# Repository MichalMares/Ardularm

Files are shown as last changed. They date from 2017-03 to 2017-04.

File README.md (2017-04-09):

# Ardularm

Ardularm is a proof-of-concept project which focuses on making an inexpensive alarm based on the Arduino platform.   
[GitHub Repository](https://github.com/MichalMares/Ardularm)

## Components and Wiring

Scheme:

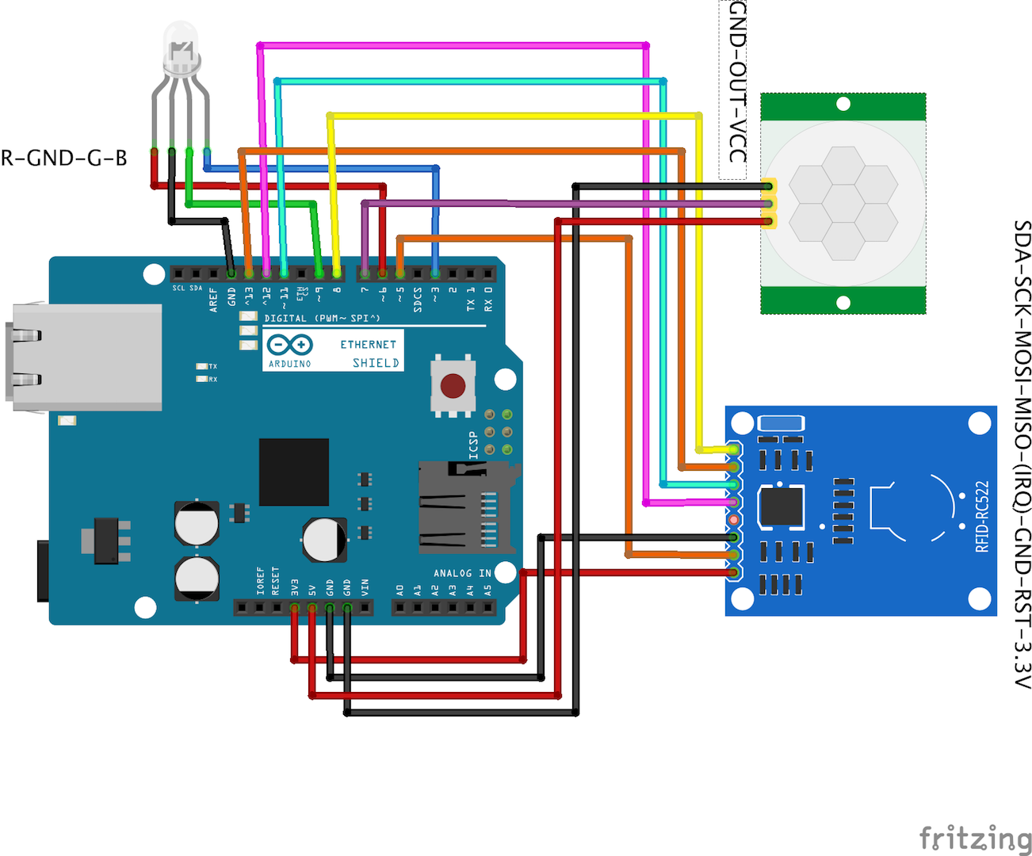
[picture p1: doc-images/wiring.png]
Wiring


You can also view this scheme in the Fritzing programme (`Wiring.fzz`).

Used components:
* Arduino UNO Rev3
* Ethernet Shield R3
* RFID Reader RC522
* Passive Infrared Sensor HC-SR501 
* Generic RGB Diode

Other components might work as well (not tested).

## Installation

Ardularm had been developed with Arduino IDE (for the Arduino code) and any other editor (for the server-side PHP code). Libraries [AddicoreRFID](http://www.addicore.com/v/vspfiles/downloadables/Product%20Downloadables/RFID_RC522/AddicoreRFID.zip)* and [Bootstrap framework](http://getbootstrap.com/) were used while creating this. To run this project on your own, there are a few steps necessary:

1. Create a database and an e-mail box on your hosting.
2. Fill in the settings file with the right credentials for your database in `Server\template.config.php` and save it as `Server\config.php`.
3. Create a `Server\.htpasswd` file with your desired user name and password (https://faq.oit.gatech.edu/content/how-do-i-do-basicauth-using-htaccess-and-htpasswd), edit path in `Server\template.htaccess` file and save it as `.htaccess`. ".htaccess" works for Apache servers only!
4. Upload the content of `Server` onto your server.
5. Run the `Server\create.php` script. This will create all the tables needed for the project and necessary values.
6. Wire up your Arduino UNO according to "Components and Wiring" section of this document.
7. Fill in the variables in `Arduino\Ardularm\Ardularm.ino` under the comment "user-configurable".
8. Upload `Arduino\Ardularm\Ardularm.ino` on your Arduino UNO using the Arduino IDE.
9. Repeat steps 6, 7, 8 for each unit you want to connect.
10. Enjoy your extra safety.

Ardularm had been developed running an Apache server with MySQL database. However, PDO should ensure it works on other SQL databases as well (not tested).

Arduino's (`Ardularm.ino`) and server's (`config.php`) "key" must correspond and can not be empty. It ensures that the POST requests come directly from the Arduino unit. If you use multiple Arduinos, "key" has to be the same for all of them.

\* The AddicoreRFID library had to be edited in order to work with Ethernet shield.

## How to use Ardularm?

**Turn alarm on/off**   
Trusted card has to be used to toggle the state. When the alarm is on the diode turns red, when off it is green (as a traffic light - green means you can enter).

**Add/remove a card to/from trusted**   
First, MasterTag has to be detected and the diode turns blue. Then you can scan your card and it will be added as trusted, if it was not trusted befor. BEWARE: If your card already is trusted, it will be REMOVED.

**Viewing the log**   
Log is located on the page `../dash.php`. Entries are sorted from newest to oldest. To search in between specific dates, enter them and click "search". If you want to leave the page running and see new entries without refreshing the page, just tick the "autorefresh" checkbox. This will refresh the page atomatically every 5 seconds.

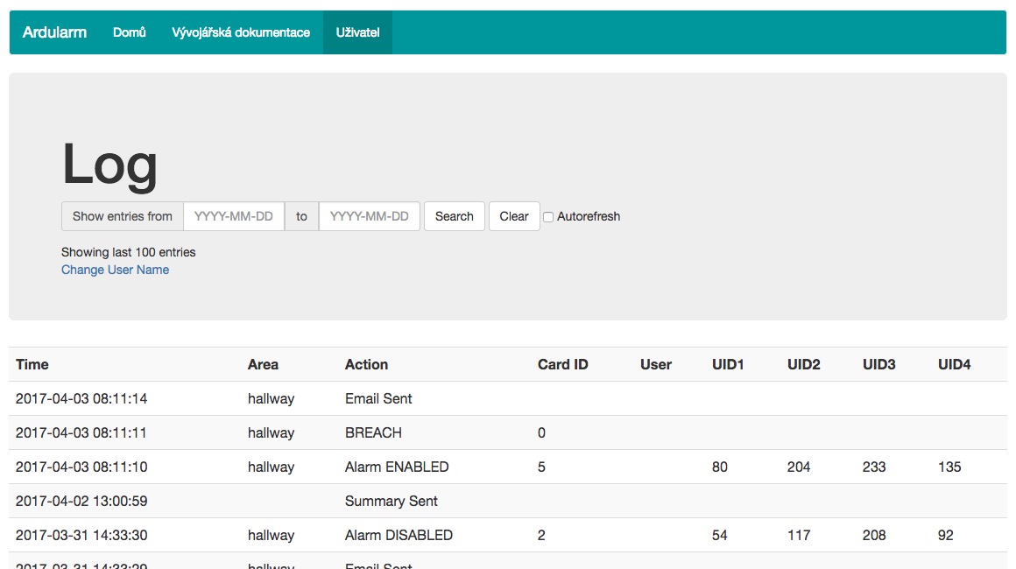
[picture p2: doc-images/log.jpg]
Log


**Editing card name**
Under the date selection on the log page, click the button "Change User Name". All four IDs must be filled in order to change the name. Successful change will be confirmed at the end of the paragraph.

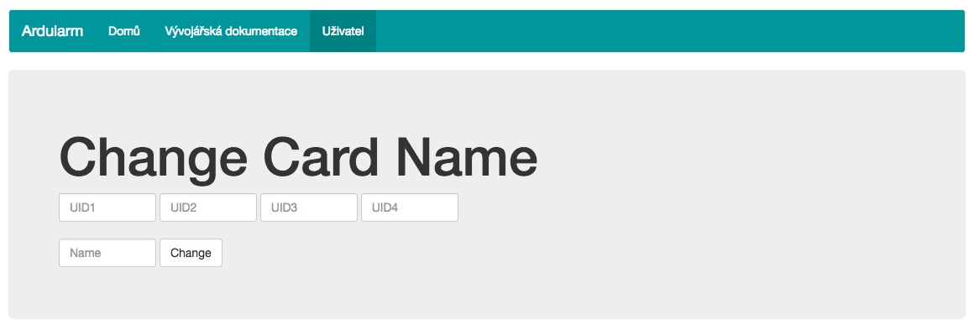
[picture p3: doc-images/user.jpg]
User


## Result

When done correctly, final product should look something like this:

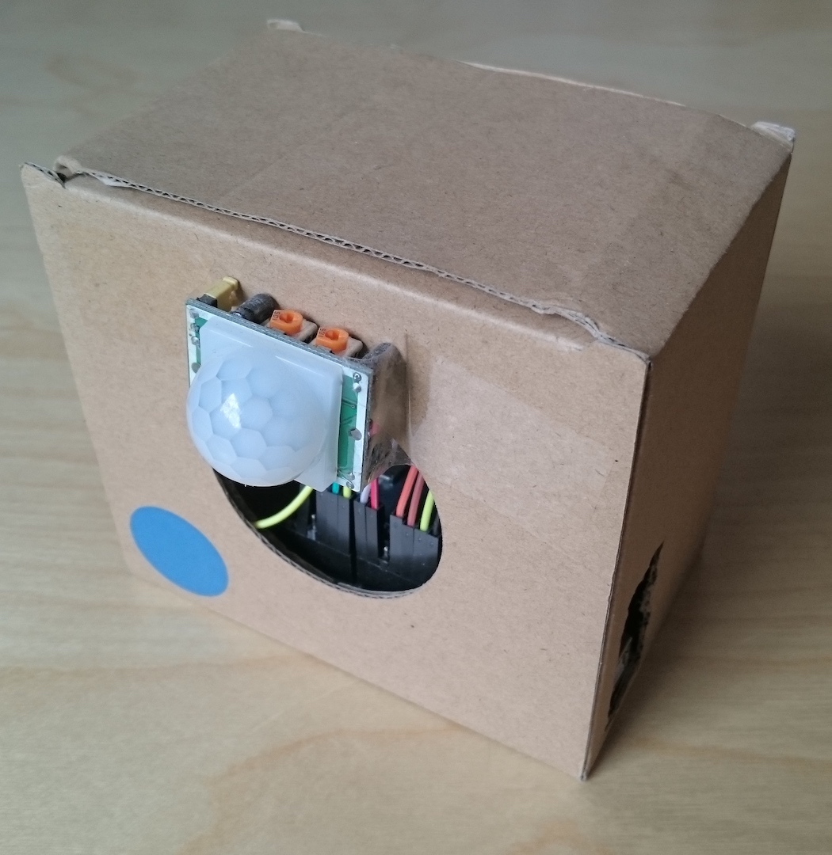
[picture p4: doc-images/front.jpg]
Front

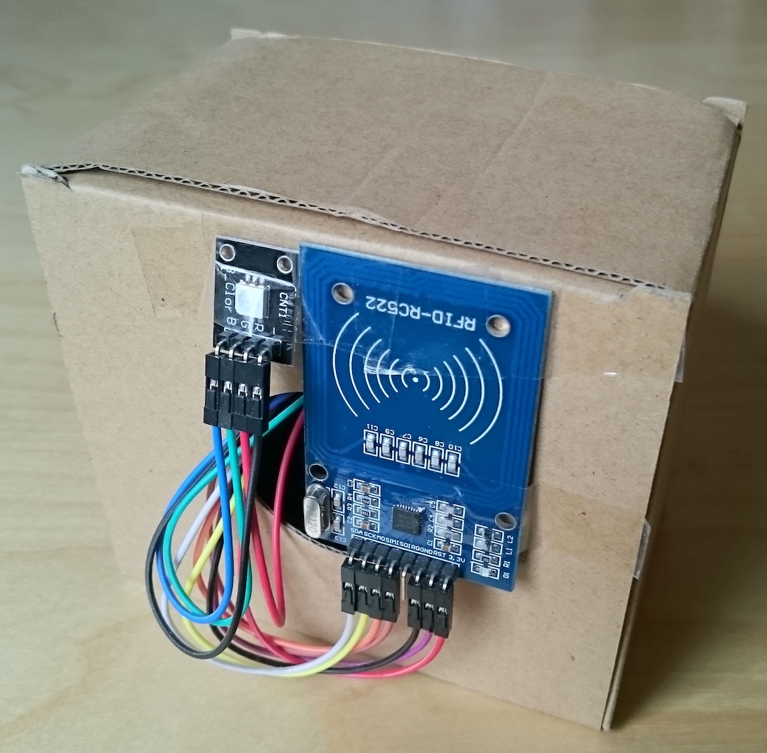
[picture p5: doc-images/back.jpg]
Back

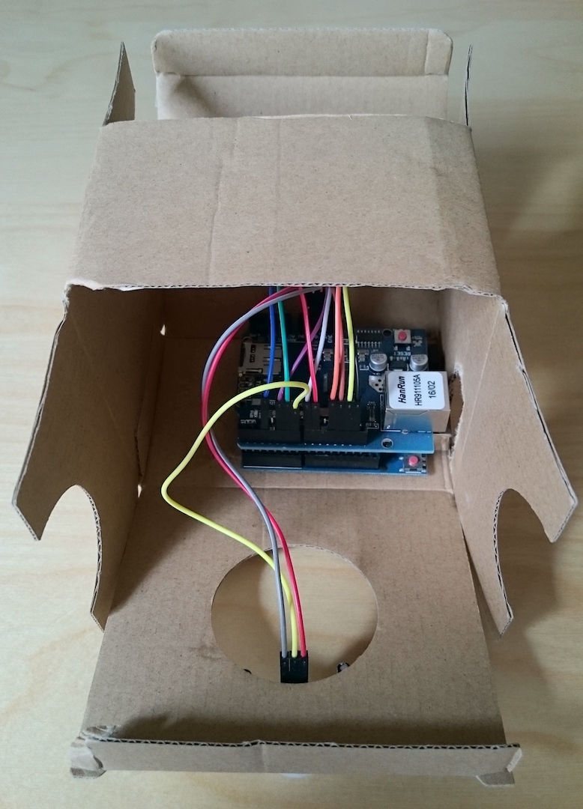
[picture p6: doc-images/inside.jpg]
Inside


The PIR sensor should face the area you want to secure and RFID reader with LED should be accessable without entering it. Of course, wires can be lengthened and mechanically protected in order to achieve this result.

## For Developers

Ardularm consists of three main parts.   
The first one is the code for Arduino unit (`Arduino\Ardularm\Ardularm.ino`), which works just like any other Arduino sketch - there is a setup() method which runs once and loop() method, which cycles for the rest of the time, running the code and calling the other methods.   
Second are the API's, which take care of the communication between Arduino and the database (`Server\api\`).   
Last is the dashboard (`Server\dash.php`) which shows the log to the user and enables some basic sorting and changing the name of the cards (`Server\user.php`).

In-depth documentation can be found in `Server\DoxyDoc\`.

Code posted here can be further developed.   
If you would like to make it work on a different Arduino board, change pin definitions at the beginning of `Arduino\Ardularm\Arduino.ino`. Mainly, SPI pins (which are pre-defined) must be changed and then connected accordingly.   
Buzzer extension is also possible: add a tone(pin, frequency) method into the `if (digitalRead(pirPin) == HIGH)` block of code and noTone() after it. [Documentation of tone()](https://www.arduino.cc/en/reference/tone)   
To send a SMS alert instead of an email, you will need something like a GSM/GPRS Shield. Instead of calling `post("sendMail", "");` in `if (digitalRead(pirPin) == HIGH)` block, you will then use sms.print() method to send a SMS according to the [official tutorial](https://www.arduino.cc/en/Tutorial/GSMExamplesSendSMS) on sending SMS.

## License

[MIT](https://github.com/MichalMares/Ardularm/blob/master/LICENSE.txt) @ [Michal Mareš](https://github.com/MichalMares)

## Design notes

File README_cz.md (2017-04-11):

# Ardularm

Ardularm je projekt, který se zabývá vytvořením levného domácího alarmu prostřednictvím platformy Arduino.   
[Repozitář na GitHubu](https://github.com/MichalMares/Ardularm)

## Komponenty a zapojení

Schéma zapojení:

Wiring

Použité součástky:
* Arduino UNO Rev3
* Ethernet Shield R3
* RFID Reader RC522
* Passive Infrared Sensor HC-SR501 
* Generic RGB Diode

Jiné součástky mohou také fungovat (netestováno).

## Instalace

Ardularm byl vytvořen pomocí Arduino IDE (kód pro Arduino) a dalším editorem (pro serverovou část, PHP kód). Knihovny [AddicoreRFID](http://www.addicore.com/v/vspfiles/downloadables/Product%20Downloadables/RFID_RC522/AddicoreRFID.zip)* a [Bootstrap framework](http://getbootstrap.com/) byly využity při vývoji. Pro instalaci projektu je potřeba:

1. Vytvořte databázi a e-mailovou schránku na vašem hostingu.
2. Upravte a vyplňte `Server\template.config.php` a uložte soubor jako `Server\config.php`.
3. Vytvořte soubor `Server\.htpasswd` se zvoleným uživatelským jménem a heslem (https://faq.oit.gatech.edu/content/how-do-i-do-basicauth-using-htaccess-and-htpasswd), přepište cestu v `Server\template.htaccess` a uložte soubor jako `.htaccess`. Zabezpečení přes htaccess platí pouze pro servery Apache!
4. Nahrajte obsah adresáře `Server` na server.
5. Spusťte `Server\create.php`. Tím automaticky vytvoříte tabulky databáze potřebné pro fungování Ardularmu.
6. Zapojte vaše Arduino UNO podle sekce "Komponenty a zapojení".
7. Vyplňte proměnné v `Arduino\Ardularm\Ardularm.ino` pod komentářem "user-configurable".
8. Nahrajte `Arduino\Ardularm\Ardularm.ino` na vaše Arduino UNO prostřednictvím Arduino IDE.
9. Opakujte kroky 6, 7, 8 pro každé zařízení, které si přejete připojit.
10. Užívejte si pocit bezpečí.

Ardularm byl vyvinut na Apache serveru s MySQL databází, nicméně PDO by mělo zajistit kompatibilitu s ostatními SQL databázemi (netestováno).

Klíč "key" Arduina (`Ardularm.ino`) musí souhlasit s klíčem severu (`config.php`) a nemůže být prázdný. Zajišťuje, že komunikace POST requestem pochází přímo z Arduina. Při použití více Arduin musí být klíče na všech stejné.

\* Knihovna AddicoreRFID musela být modifikována, aby fungovala paralelně s Ethernet Shield.

## Návod k použití

**Zapnutí/vypnutí alarmu**   
Pouze důvěryhodné karty mohou přepínat stav alarmu. Pokud je alarm aktivní, svítí červeně, pokud neaktivní, zeleně (jako semafor - zelená znamená, že můžete projít).

**Přidat/odebrat kartu do/z důvěryhodných**   
Nejdříve je potřeba načíst MasterTag (administrátorská karta) a vyčkat, než se dioda rozsvítí modře. Pak lze načíst další kartu, která bude zaevidována jako důvěryhodná, pokud předtím nebyla. POZOR: Pokud karta již byla důvěryhodná, bude z důvěryhodných ODEBRÁNA.

**Zobrazení událostí**   
Zobrazení událostí je možné v logu na `../dash.php`. Záznamy jsou seřazeny od nejnovějšího po nejstarší. Pro vyhledání v určitém časovém období, vyplňte data a stiskněte tlačítko "search". Pokud chcete stránku nechat spuštěnou a vidět nové záznamy, zatrhněte "atorefresh". Stránka se pak bude obnovovat s frekvencí 5 sekund.

Log

**Změna jména karty**
Pod výběrem data u logu klikněte na "Change User Name". Všechny čtyři identifikační čísla musí být vyplněny, aby mohlo být změněno jméno. Úspěšná změna bude potvrzena oznámením na konci odstavce.

User

## Výsledek

Při správném postupu by měl konečný výtvor vypadat podobně:

Front
Back
Inside

Infračervený senzor by měl směřovat do prostoru, který si přejete zajistit, RFID čtečka spolu s LED by pak měla být přístupná bez narušení tohoto prostoru. Vodiče mohou být samozřejmě prodlouženy a mechanicky chráněny pro dosažení takového výsledku.

## Licence

[MIT](https://github.com/MichalMares/Ardularm/blob/master/LICENSE.txt) @ [Michal Mareš](https://github.com/MichalMares)

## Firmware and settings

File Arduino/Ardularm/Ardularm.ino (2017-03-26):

/**
 * @file Ardularm.ino
 * @Author Michal Mareš
 * @date March, 2017
 * @brief The code running on Arduino unit.
 */

#include <AddicoreRFID.h>
#include <Ethernet.h>
#include <SPI.h>

// user-configurable
char server[] = "domain.tld"; /// Domain.
String key = "password"; /// Password for running PHP scripts.
String area = "location"; /// Location of this Ardularm.
int masterTag[] = {255, 255, 255, 255}; /// UIDs of the MasterTag.
byte mac[] = {0x00, 0xAA, 0xBB, 0xCC, 0x2E, 0x02}; /// Arduino Mac Address.

boolean alarmState = false; // beginning state of the alarm
unsigned long previousMillis = 0; // will store last time of checking the server
const long interval = 30000; // interval at which to act (in milliseconds)

// RGB LED pins
#define red 6
#define green 9
#define blue 3

// RFID variables
#define uchar unsigned char
#define uint  unsigned int
#define MAX_LEN 16 // maximum length of the RFID array
uchar fifobytes;
uchar fifoValue;

AddicoreRFID myRFID;
EthernetClient client;

const int ssSD = 4; // SD slave select pin
const int ssEthernet = 10; // Ethernet chip slave select pin
const int chipSelectPin = 8; // RFID slave select pin
const int NRSTPD = 5; // RFID reset pin
const int pirPin = 7; // PIR sensor pin

void setup() {
  Serial.begin(9600);
  SPI.begin();

  Serial.println("Initializing...");

  // enable PIR sensor
  pinMode(pirPin, INPUT);
  digitalWrite(pirPin, LOW);

  // start RFID reader
  pinMode(chipSelectPin, OUTPUT); // set digital pin 8 as OUTPUT to connect it to the RFID /ENABLE pin
  digitalWrite(chipSelectPin, LOW);
  pinMode(NRSTPD, OUTPUT); // set digital pin 5 , not reset and power-down
  digitalWrite(NRSTPD, HIGH);
  myRFID.AddicoreRFID_Init();

  // disable SD card
  pinMode(ssSD, OUTPUT);
  digitalWrite(ssSD, HIGH);

  // start Ethernet connection
  if (Ethernet.begin(mac) == 0) {
    Serial.println("Failed to configure Ethernet using DHCP");
  }
  delay(1000);

  printIPAddress();
  manageState("sync");
  post("addEntry", "action=Power ON");
  
  Serial.println("--- READY ---");
  Serial.println();
}

void loop() {
  uchar i, tmp;
  uchar status;
  uchar str[MAX_LEN];
  uchar RC_size;
  uchar blockAddr;  // Selection operation block address 0 to 63
  String mynum = "";
  str[1] = 0x4400;

  status = myRFID.AddicoreRFID_Request(PICC_REQIDL, str); // find tags, return tag type
  status = myRFID.AddicoreRFID_Anticoll(str); // anti-collision, return tag serial number 4 bytes

  if (status == MI_OK) {
    int sourceTag[] = {str[0], str[1], str[2], str[3], str[4]};

    // MasterTag detected and alarm is not on
    if (checkMaster(sourceTag) == true && alarmState == false) {
      Serial.println("MasterTag detected, waiting for another tag...");
      led(0,0,50);
      myRFID.AddicoreRFID_Halt();
      str[1] = 0x4400;
      while (status == MI_OK) {
        status = myRFID.AddicoreRFID_Request(PICC_REQIDL, str);
        status = myRFID.AddicoreRFID_Anticoll(str);
      }
      delay(1000);
      while (status != MI_OK) {
        status = myRFID.AddicoreRFID_Request(PICC_REQIDL, str);
        status = myRFID.AddicoreRFID_Anticoll(str);
      }

      if (status == MI_OK) {
        led(50,50,0);
        int sourceTag[] = {str[0], str[1], str[2], str[3], str[4]};
        readTag(sourceTag);

        String data = "uid1=" + String(sourceTag[0]) + "&uid2=" + String(sourceTag[1]) + "&uid3=" + String(sourceTag[2]) + "&uid4=" + String(sourceTag[3]);
        post("manageTags", data); // pass tag to the manageTags.php script
      }
    }

    // normal tag detected
    else {
      readTag(sourceTag);
      led(50,50,0);
      Serial.print("Is tag trusted? ");
      boolean trusted = verifyTrusted(sourceTag); // check if tag is trusted or not
      if (trusted == true) {
        alarmToggle(sourceTag); // trusted -> toggle alarm
      }
      else if (trusted == false) {
        String action = "Access DENIED";
        String data = "uid1=" + String(sourceTag[0]) + "&uid2=" + String(sourceTag[1]) + "&uid3=" + String(sourceTag[2]) + "&uid4=" + String(sourceTag[3]) + "&action=" + String(action);
        post("addEntry", data); // not trusted -> add entry to db
      }
    }
    Serial.println();
    delay(500);
  }

  myRFID.AddicoreRFID_Halt(); // Command tag into hibernation

  // check server for state if the interval has passed
  unsigned long currentMillis = millis();
  if (currentMillis - previousMillis >= interval) {
    previousMillis = currentMillis; // save the last time you checked server
    manageState("sync"); // synchronizes the state with server
  }

  // check PIR sensor
  if (alarmState == true) {
    led(50,0,0); // switch led to red color

    if (digitalRead(pirPin) == HIGH) { // send email and add entry
      post("addEntry", "action=BREACH");

      while (digitalRead(pirPin) == HIGH) { // flash until sensor cools down
        led(50,0,0);
        delay(100);
        led(0,0,0);
        delay(100);
      }

      post("sendMail", "");
    }
  }

  if (alarmState == false) { // switch led to green color
    led(0,50,0);
  }
}

/**
 * Default Arduino fuction for printing device IP address.
 */
void printIPAddress() {
  Serial.print("My IP address: ");

  for (byte thisByte = 0; thisByte < 4; thisByte++) {
    Serial.print(Ethernet.localIP()[thisByte], DEC);
    Serial.print(".");
  }

  Serial.println();
}

/**
 * Compares read tag with pre-set MasterTag.
 * @param  sourceTag Array of UIDs of the read tag.
 * @return           Returns true when they agree and false when they differ.
 */
boolean checkMaster(int sourceTag[]) {
  for (int i=0; i<4; i++) {
    if (sourceTag[i] != masterTag[i]) {
      return false;
    }
  }
  return true;
}

/**
 * Runs the manageState.php script on the server and either "gets"
 * a value from database, or "chages" the database entry.
 * @param option Either "get" or "change", option is then passed on to the manageState.php.
 */
void manageState(String option) {
  String data = "option=" + option;
  if (option == "sync") {
    String response = post("manageState", data);
    if (response == "Sync: alarmState=1") {
      alarmState = true;
    } else {
      alarmState = false;
    }
  }
  else if (option == "change") {
    post("manageState", data);
  }
}

/**
 * Toggles the alarmState value and adds an entry into the database.
 * @param  sourceTag Array of UIDs of the read tag.
 */
void alarmToggle(int sourceTag[]) {
  alarmState = !alarmState;

  String action;
  if (alarmState == true) {
    action = "Alarm ENABLED";
    manageState("change");
  }
  else if (alarmState == false) {
    action = "Alarm DISABLED";
    manageState("change");
  }

  String data = "uid1=" + String(sourceTag[0]) + "&uid2=" + String(sourceTag[1])
    + "&uid3=" + String(sourceTag[2]) + "&uid4=" + String(sourceTag[3]) + "&action=" + String(action);
  post("addEntry", data);
}

/**
 * Sends UIDs to the verifyTrusted.php script which checks the database and
 * evaluates the response.
 * @param  sourceTag Array of UIDs of the read tag.
 * @return           Returns true when it is trusted, false when not trusted.
 */
boolean verifyTrusted(int sourceTag[]) {
  String data = "uid1=" + String(sourceTag[0]) + "&uid2=" + String(sourceTag[1])
    + "&uid3=" + String(sourceTag[2]) + "&uid4=" + String(sourceTag[3]);

  String response = post("verifyTrusted", data);

  if (response == "trusted=1") {
    return true;
  } else {
    return false;
  }
}

/**
 * Calls corresponding script on the server via POST request.
 * @param  page The name of the script without the ".php" suffix.
 * @param  data String to be sent as data for the script.
 * @return      Returns the response of the server.
 */
String post(String page, String data) {
  data += "&key=" + key + "&area=" + area;
  String response;

  if (client.connect(server, 80)) {
    client.println("POST /api/" + page + ".php HTTP/1.1");
    client.println("Host: " + String(server));
    client.println("Content-Type: application/x-www-form-urlencoded");
    client.println("Content-Length: " + String(data.length()) );
    client.println();
    client.println(data);
  } else {
    client.stop();
    Serial.println("*disconnected*");
    return response = "*disconnected*";
  }

  response = getResponse();
  Serial.println(response);

  client.stop();
  return response;
}

/**
 * Looks for script's response enclosed within "<" and ">".
 * @return Returns the response of the server.
 */
String getResponse() {
  String output = "";
  boolean insideResp = false;

  for (int i = 0; i < 25000; i++) { // allows maximum message length X chars, can be changed if needed
    if (client.available()) {
      char c = client.read();
      String str = String(c);

      if (str == "{") {
        insideResp = true;
      }
      else if (insideResp == true) {
        if (str != "}") {
          output += str;
        }
        else {
          return output;
        }
      }
    }
  }
  return output = "ERROR: Response Not Found";
}

/**
 * Lights up the LED with corresponding color.
 * @param redVal   Red value [0-255].
 * @param greenVal Green value [0-255].
 * @param blueVal  Blue value [0-255].
 */
void led(int redVal, int greenVal, int blueVal) {
  analogWrite(red, redVal);
  analogWrite(green, greenVal);
  analogWrite(blue, blueVal);
}

/**
 * Prints the UIDs of the tag into the Serial.
 * @param sourceTag Array of UIDs of the read tag.
 */
void readTag(int sourceTag[]) {
  uchar checksum = sourceTag[0] ^ sourceTag[1] ^ sourceTag[2] ^ sourceTag[3];

  Serial.print("The tag's number is:\t");
  for (int i = 0; i < 3; i++) {
    Serial.print(String(sourceTag[i]) + ", ");
  }
  Serial.println(sourceTag[3]);

  Serial.print("Read Checksum:\t\t");
  Serial.println(sourceTag[4]);
  Serial.print("Calculated Checksum:\t");
  Serial.println(checksum);
}

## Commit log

2017-03-10 Switched to PDO
2017-03-10 Major bug fixes, LED
    [Ardularm.ino]
2017-03-10 Further improvements
    - added authentication between Arduino and server
    - started using PHPMailer for email communication
    - added search for index page
    - a lot more…
2017-03-13 Web redesign with Bootstrap, tweaks and bug fixes
    [Ardularm.ino]
2017-03-23 Update config.php and some minor changes
    [Ardularm.fzz]
2017-03-25 Add area, update README
    [Ardularm (wiring).fzz, Ardularm.fzz]
2017-03-30 Switch to HTML
2017-03-30 Add PNG to README.md
    [Wiring.fzz]
